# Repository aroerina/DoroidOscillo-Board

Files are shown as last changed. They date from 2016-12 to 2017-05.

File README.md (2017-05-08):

DroidOscillo KiCAD Board data

## Description
DroidOscillo KiCAD board data  
Schematic is here  
https://github.com/aroerina/DroidOscillo-Photos/blob/master/Schematic.pdf

## Building tools
KiCAD 4.0.2

## Parts description
U1 LPC4370FET100 - Main MCU.204MHz triple core(Cortex M4 + M0 * 2) and includes 80Msps ADC.  
U5 OPA4354 - Quad cmos opamp.  
U14 MCP4726A0T-E/CH - 12bit I2C DAC.  

## Related repositorys

DroidOscillo Firmware: https://github.com/aroerina/DroidOscillo-Firmaware  
DroidOscillo Android host: https://github.com/aroerina/DroidOscillo-Android_host  

## Wiki
https://github.com/aroerina/DroidOscillo-Android_host/wiki

## Licence

DroidOscillo Hardware is released under the [CC BY-NC 4.0](https://creativecommons.org/licenses/by-nc/4.0/)
CC BY

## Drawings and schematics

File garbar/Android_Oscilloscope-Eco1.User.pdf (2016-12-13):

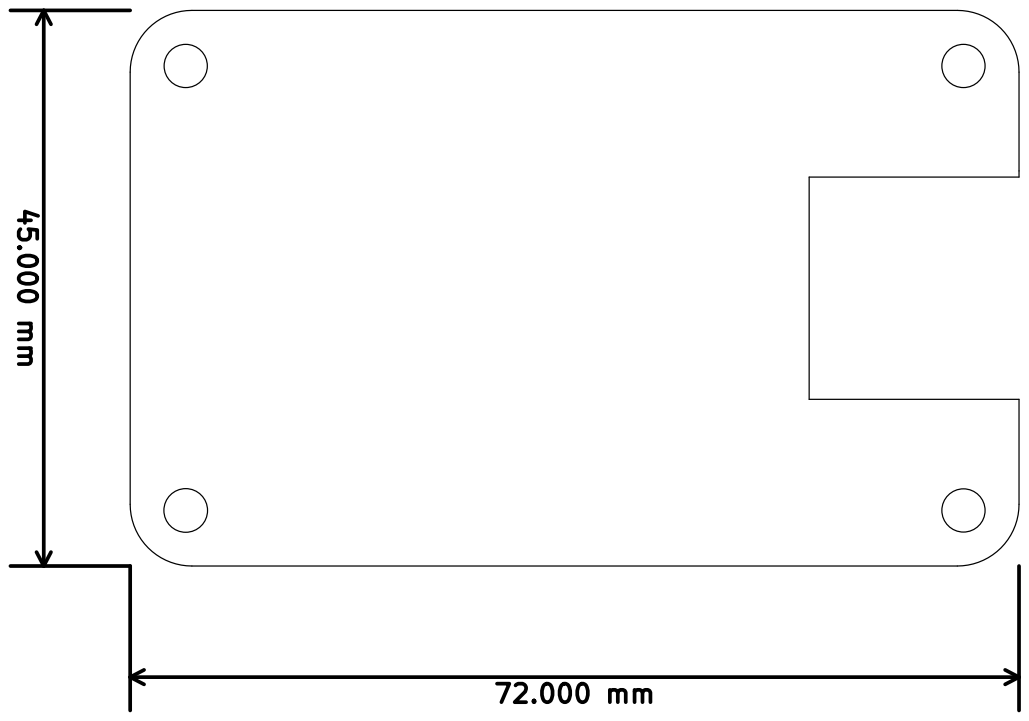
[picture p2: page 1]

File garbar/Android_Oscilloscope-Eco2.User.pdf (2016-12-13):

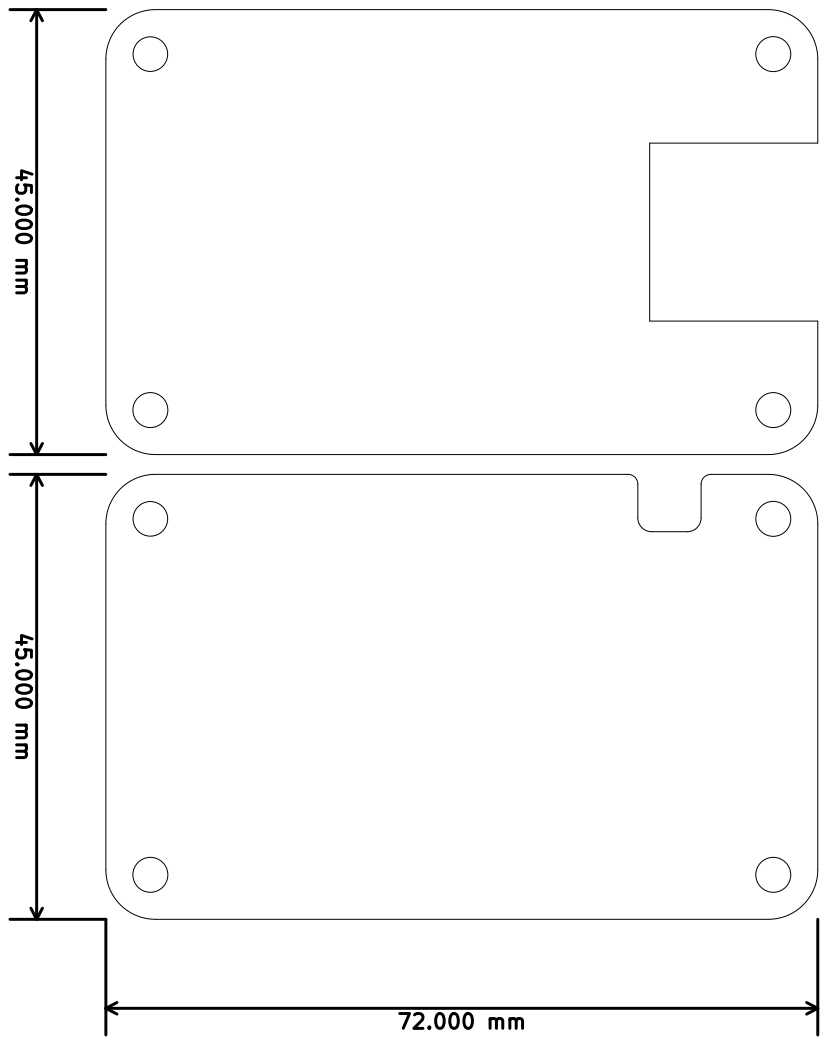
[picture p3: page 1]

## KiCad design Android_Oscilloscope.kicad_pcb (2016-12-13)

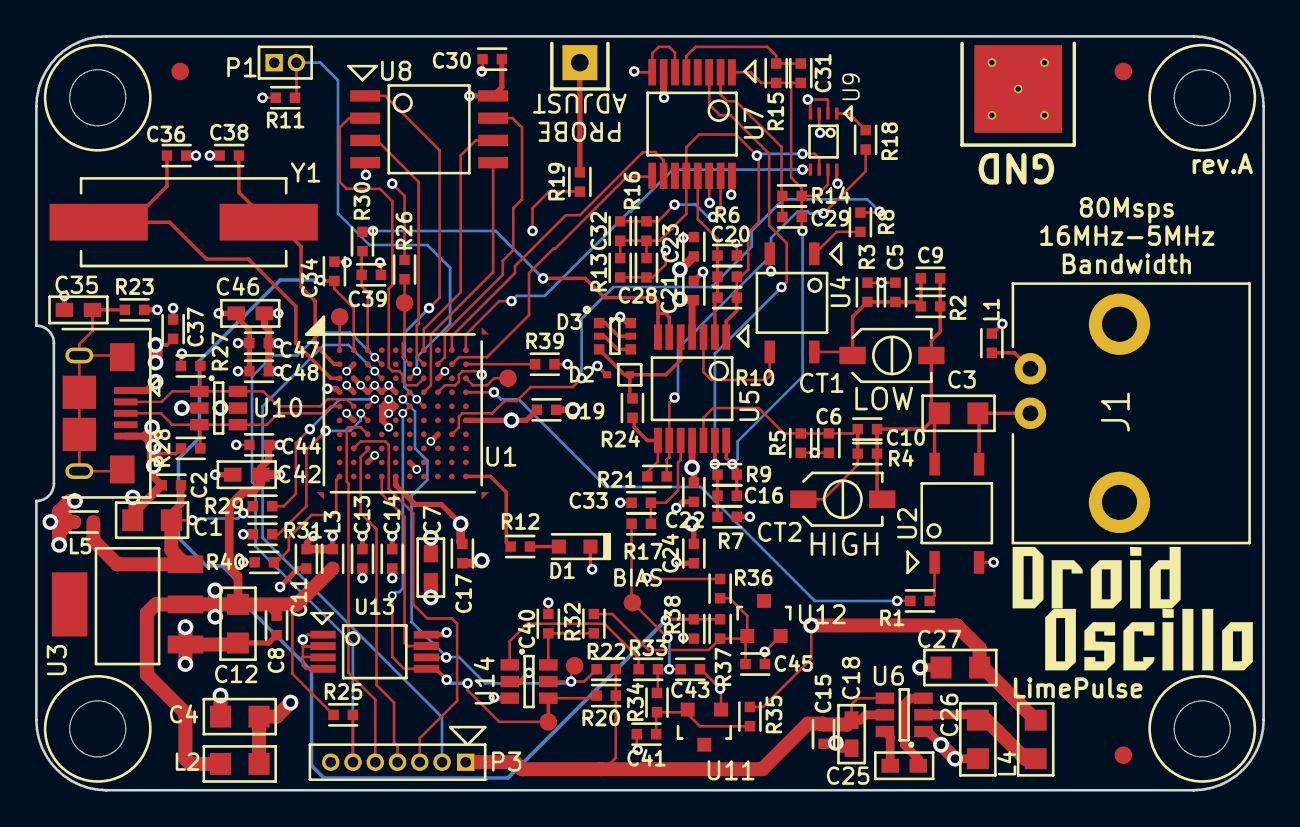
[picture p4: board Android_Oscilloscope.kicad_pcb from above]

Board: 4 copper layers, 70.0 x 43.0 mm, 132 parts (0 on the bottom side), 77 nets.

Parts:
C1, C4, C12, C26, C27: 22u 6.3V; SMD2012
C2, C8, C11, C14, C15, C17, C19, C23, C24, C30, C33, C37, C41, C43, C44, C45, C47: 0.1u; SMD1005
C3: 47n 100V; SMD2012
C5, C32: 4.7p; SMD1005
C6: 120p; SMD1005
C7, C18, C42, C46: 10u 6.3V; SMD1608
C9, C10, C39: NM; SMD1005
C13, C48: 22n; SMD1005
C16, C20: 2.2p; SMD1005
C21, C22, C34, C40: 1u; SMD1005
C25: 4.7u 6.3V; SMD1608
C28: 15p; SMD1005
C29: 3.3p; SMD1005
C31: 10p; SMD1005
C35: 4.7n 100V; SMD1608
C36, C38: 18p; SMD1005
CT1: TZC3R100A110 3p-10p; MURATA_TZC3
CT2: TZC3Z030A110R00 1.4p-3p; MURATA_TZC3
D1: APT1608EC; SMD1608_DIODE
D2: RB521S30T5G; SOD-523
D3: BAS16VY; SOT-363
FID1: Fiducial_C; Fiducial_1mm
FID2: Fiducial_A; Fiducial_1mm
FID3: Fiducial_B; Fiducial_1mm
HOLE3MM_NC, HOLE3MM_NC#2, HOLE3MM_NC#3, HOLE3MM_NC#4: VAL**; HOLE3MM_NC
J1: BNC; BNC-R
L1, L5: BLM15AG121SN1; SMD1005
L2, L4: LBR2012T202K; SMD2012
L3: BLM15AG601SN1; SMD1005
P1: USB_BOOT; PIN_HEADER_2_1.27mm
P2: FCI_10118193-0001LF; 10118193-0001LF
P3: JTAG; PIN_HEADER_7_1.27pitch
R1, R8, R11, R36, R39, R40: 2.2k 5%; SMD1005
R2: 1100k 1%; SMD1005
R3: 910k 1%; SMD1005
R4: 1.96M 1%; SMD1005
R5: 36k 1%; SMD1005
R6, R7: 3k 1%; SMD1005
R9, R10: 27k 1%; SMD1005
R12: 10k 5%; SMD1005
R13: 3.3k 1%; SMD1005
R14: 22k 1%; SMD1005
R15: 5.6k 1%; SMD1005
R16: 13.3k 1%; SMD1005
R17, R32: 4.7k 5%; SMD1005
R18: 910 1%; SMD1005
R19, R29: 100 5%; SMD1005
R20, R22, R25, R26: 4.7k; SMD1005
R21: 1k 1%; SMD1005
R23, R27, R28: 1M 5%; SMD1005
R24: 680 1%; SMD1005
R30: 0; SMD1005
R31: 12k 1%; SMD1005
R33: 2k 1%; SMD1005
R34: 8.2k 1%; SMD1005
R35, R38: 1.5k 1%; SMD1005
R37: 2.2k 1%; SMD1005
TP1: SCL; TestPad
TP2: SDA; TestPad
TP3: RST; TestPad
U1: LPC4370FET100; TFBGA100_MYREFLOW
U2, U4: CPC1017N
U3: AMS1117-3.3; SOT-223
U5: OPA4354AIPWR; TSSOP-14_4.4x5mm_Pitch0.65mm
U6: LM2664; SOT-23-6
U7: 74HC4052PW; TSSOP-16_4.4x5mm_Pitch0.65mm
U8: W25Q80BVSSIG; SOIJ-8_5.3x5.3mm_Pitch1.27mm
U9: TC7W53FK; SSOP8_P0.5W2.3
U10: USBLC6-2SC6; SOT-23-6
U11, U12: LM385M3-1.2/NOPB; SOT-23
U13: AT24C02C-XHM-T; TSSOP-8_4.4x3mm_Pitch0.65mm
U14: MCP4726A0T-E/CH; SOT-23-6
W1: ISP; TestPad
W2: PROBE_COMP_HOLE
W3: ADC1; TestPad
W4: PROBE_GND_PAD; Probe-ADJ-GND
W5: TP_BIAS; TestPad
Y1: ABLS-12.000MHZ-B4-T; Crystal_HC49-SD_SMD

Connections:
/USB_D+: P2.3, R28.1, U1.E1, U10.3, U10.4
/USB_D-: P2.2, R27.1, U1.E2, U10.1, U10.6
/USB_VBUS: R29.1, U1.E3
ADCHS_VNEG: C39.1, R30.2, U1.A3
ADCHS_VPOS0: C34.1, R37.2, R38.1, U1.A2
BIAS: C43.2, R17.1, R33.2, R34.1, W5.1
BOOT1: R40.1, U1.K1
BOOT2: P1.2, R11.1, U1.C6
BOOT3: R39.1, U1.B10
BOOT_ISP: U1.C10, W1.1
DAC_OUT: R33.1, U14.1
DAC_VREF: C45.1, R32.1, R36.2, R37.1, U12.1
DC_SW: R1.1, U1.D10
EEPROM_WP: U1.K4, U13.7
GND: C1.2, C2.2, C4.2, C5.2, C6.2, C7.2, C8.2, C11.2, C12.2, C13.2, C14.2, C15.2, C17.2, C18.2, C19.2, C21.2, C22.1, C23.2, C24.1, C26.2, C27.2, C30.2, C33.2, C34.2, C35.2, C36.1, C37.2, C38.1, C39.2, C40.1, C41.2, C42.2, C43.1, C44.2, C45.2, C46.2, C47.2, C48.2, D1.1, D2.2, D3.6, L1.2, P2.5, P3.7, R3.1, R5.2, R6.2, R7.2, R11.2, R23.2, R27.2, R28.2, R31.2, R38.2, R39.2, R40.2, U1.C2, U1.C8, U1.D3, U1.D4, U1.D5, U1.F2, U1.G8, U1.J3, U1.J6, U2.2, U3.1, U4.2, U6.1, U7.6, U7.8, U8.4, U9.2, U9.4, U10.2, U11.1, U12.2, U13.1, U13.2, U13.3, U13.4, U14.2, W4.1
I2C_SCL: R22.2, TP1.1, U1.D6, U13.6, U14.5
I2C_SDA: R20.2, TP2.1, U1.E6, U13.5, U14.4
JTAG_RESET: P3.6, R25.2, U1.B4
JTAG_TCK: P3.3, U1.H2
JTAG_TDI: P3.5, U1.G3
JTAG_TDO: P3.4, U1.H3
JTAG_TMS: P3.2, U1.C4
LED0: R12.1, U1.K10
MUX0-S0: U1.A9, U7.10
MUX0-S1: U1.B9, U7.9
MUX1-A: U1.A10, U9.5
unnamed: C3.1, J1.C, U2.3
unnamed: C5.1, C9.2, CT1.2, R2.1, R3.2, U4.4
unnamed: C3.2, C9.1, C10.1, CT1.1, CT2.1, R2.2, R4.1, U2.4
unnamed: C6.1, C10.2, CT2.2, R4.2, R5.1, U5.12
unnamed: C7.1, C11.1, C13.1, C14.1, L3.2, U1.E4, U1.E5, U1.F4
unnamed: C16.1, C29.2, C31.2, R9.2, R14.2, R15.2, U5.14, U7.1, U9.7
unnamed: C16.2, R7.1, R9.1, U5.13, U7.3
unnamed: C20.1, R6.1, R10.2, U5.2, U7.13
unnamed: C20.2, C28.1, C32.1, R10.1, R13.1, R16.1, U5.1, U7.12, U9.6
unnamed: C25.1, U6.6
unnamed: C25.2, U6.3
unnamed: C26.1, L4.1, U6.2
unnamed: C28.2, R13.2, U7.14
unnamed: C29.1, R14.1, U7.2
unnamed: C31.1, R15.1, U7.5
unnamed: C32.2, R16.2, U7.15
unnamed: C33.1, R17.2, U5.10
unnamed: C35.1, P2.S1, P2.S2, P2.S3, P2.S4, P2.S5, P2.S6, R23.1
unnamed: C36.2, U1.C1, Y1.1
unnamed: C37.1, L5.1, P2.1, U10.5
unnamed: C38.2, U1.B1, Y1.2
unnamed: C40.2, R32.2, U14.6
unnamed: C41.1, R34.2, R35.1, U11.2
unnamed: D1.2, R12.2
unnamed: D2.1, D3.3, R24.2, U5.5
unnamed: D3.1, D3.5
unnamed: D3.2, D3.4
unnamed: J1.S, L1.1
unnamed: R1.2, U2.1
unnamed: R8.1, U4.1
unnamed: R18.1, R21.2, U5.9
unnamed: R18.2, U9.1
unnamed: R19.1, W2.1
unnamed: R21.1, R24.1, U5.8
unnamed: R26.2, TP3.1, U1.B6
unnamed: R30.1, U5.6, U5.7
unnamed: R31.1, U1.F3
unnamed: U1.A1, W3.1
unnamed: U4.3, U5.3
OP_SW: R8.2, U1.G9
PROBE_COMP: R19.2, U1.D8
SPIFI_CS: U1.E7, U8.1
SPIFI_MISO: U1.C7, U8.2
SPIFI_MOSI: U1.D7, U8.5
SPIFI_SCK: U1.A7, U8.6
SPIFI_SIO2: U1.B7, U8.3
SPIFI_SIO3: U1.B8, U8.7
VBUS: C1.1, C2.1, L5.2, R29.2, U3.3
alt_3.3VD: C8.1, C12.1, C15.1, C17.1, C18.1, C19.1, C30.1, C42.1, C44.1, C46.1, C47.1, C48.1, L2.1, L3.1, P1.1, P3.1, R20.1, R22.1, R25.1, R26.1, U1.B2, U1.D1, U1.D2, U1.F10, U1.K5, U3.2, U6.4, U6.5, U8.8, U13.8
alt_VAA+: C4.1, C21.1, C23.1, L2.2, R36.1, U5.4, U7.16, U9.8, U14.3
alt_VAA-: C22.2, C24.2, C27.1, L4.2, R35.2, U5.11, U7.7, U9.3
